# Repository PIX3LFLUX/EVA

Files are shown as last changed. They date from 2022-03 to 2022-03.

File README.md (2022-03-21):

# Electric slot Vehicle Automation (EVA)
An autonomous slot car for Carrera Digital 124 / 132, project with hardware and software components.
It's  written with PlatformIO using the Arduino framework.

## The Hardware
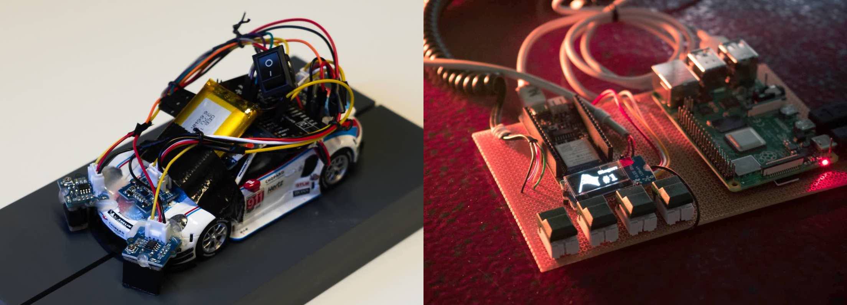
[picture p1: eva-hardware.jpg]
EVA Hardware


## General Information
This project was the author's Bachelor's Thesis at Hochschule Karlsruhe (HKA).
Documentation of the project as a whole is thus only available in german language.
The repository contents (including code comments) are english to ease adaption.

## Getting Started
### Prerequisites
- Python  
```
https://www.python.org/downloads/
```
Tick the "add to PATH" option just in case.
- Visual Studio Code  
```
https://code.visualstudio.com/Download
```
- PlatformIO IDE  
Open VSCode, then find the Extensions Marketplace on the left hand side or press Ctrl+Shift+X.
Search for "PlatformIO".
Once found, install it by clicking on "install".
- C/C++ Extension Pack  
Install it in the same way as PlatformIO IDE.

*Optional*
- Matlab  
```
https://www.mathworks.com/products/get-matlab.html
```
The project includes several Matlab scripts to aid development.
If Matlab is not available to You, try adjusting the syntax to use Octave instead.
```
https://www.gnu.org/software/octave/download
```

### Installation
- Download the code from this repository as a zip file.
- Unpack the archive into your working directory.
- Open VSCode.
- In VSCode, navigate to File > Open Folder or press Ctrl + K followed by Ctrl + O.
- Choose either "controller_emulator_status_monitor" or "datalogger_sensorcar" from this repository to open the respective project.
- In the EXPLORER on the left hand side, open the .vscode directory and click on c_cpp_properties.json. This will update the file to represent the paths on your development machine.
- On the bottom panel, click on the checkmark to build the project.
- Connect the ESP32 microcontroller to the development PC via USB.
- On the bottom panel, press the arrow pointing to the right to upload the code to the microcontroller.
- The code from "datalogger_sensorcar" is flashed to the vehicle, the code from "controller_emulator_status_monitor" is flashed to the stationary part of the system.
- To get a serial interface to the microcontroller for debugging, press the plug symbol on the bottom panel.
- Set up a Raspberry Pi 4 according to the instructions in "tools/pi-conf/instructions-to-setup-raspi" if output to a 1080p HDMI display is needed.  

*Optional*
- In VSCode, navigate to File > Preferences > Settings or press Ctrl+,.
- Search for "word wrap", then change "Editor: Word Wrap" from "off" to "on". The source code is designed to be viewed with word wrap.

## Usage
- You can find "globals.h" in the "include" folder using the EXPLORER on the left hand side.
- In both projects, this file is used to change behavior of the whole program easily.
- A description for every parameter is given as a comment in the file.
- State constants such as "SENSORCAR_IDLE_STATE" are not intended to be changed, as they are merely macros to make the code more readable.
- Extern variables that are declared in "globals.h" are initialized in "globals.cpp".
- The "tools" folder contains files that are used to assist development and are not required for functionaliy.

## Contributing
If you have a suggestion that would make this better, please fork the repository.
The author has finished development and will thus not be able to accept and process pull or feature requests.

## License
Distributed under the MIT License. See "LICENSE.txt" for more information.

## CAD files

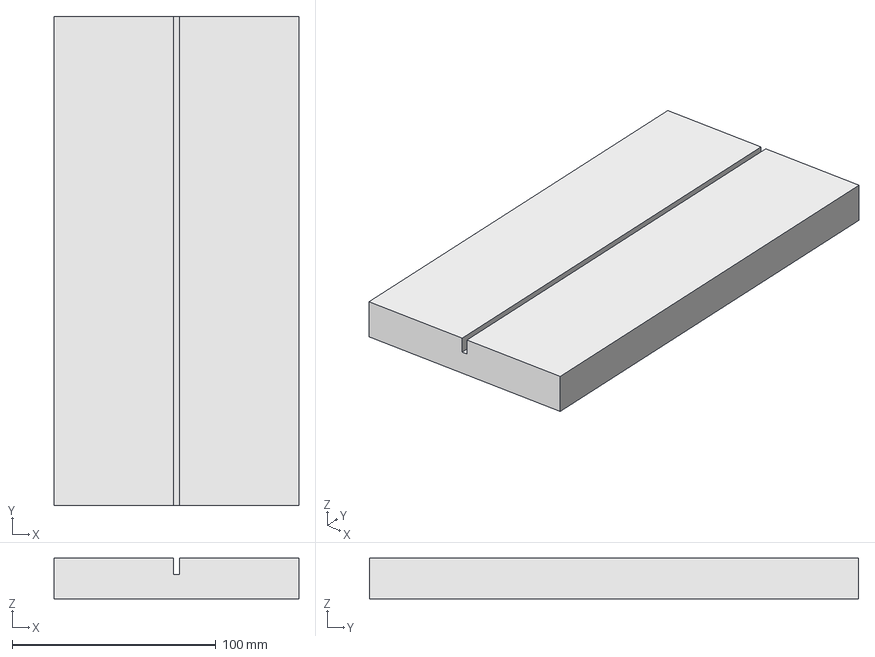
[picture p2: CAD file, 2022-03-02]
tools/imu-axes-calibration/calibration-block.FCStd
120.0 x 240.0 x 20.0 mm

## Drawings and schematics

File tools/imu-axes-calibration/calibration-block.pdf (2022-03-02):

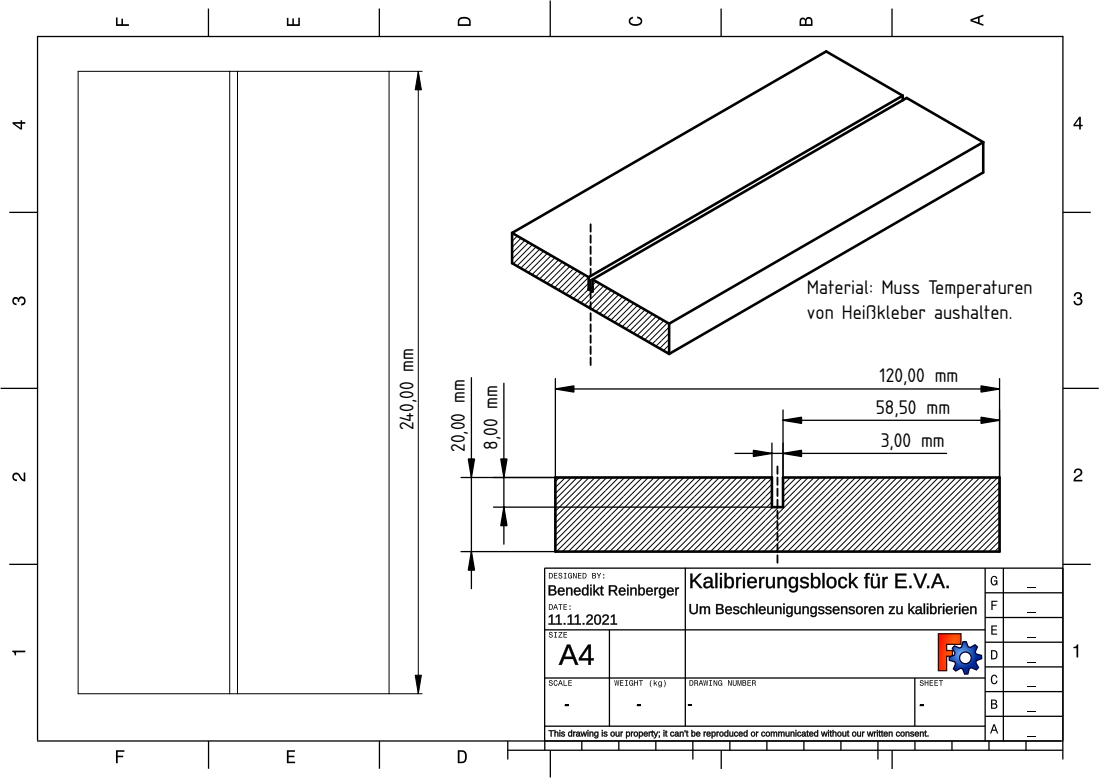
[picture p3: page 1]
aterial: M; erature; eiß; kle; alte

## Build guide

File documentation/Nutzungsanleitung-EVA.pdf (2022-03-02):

## EVA - Electric slot Vehicle Automation

## METHODEN UND HERAUSFORDERUNGEN

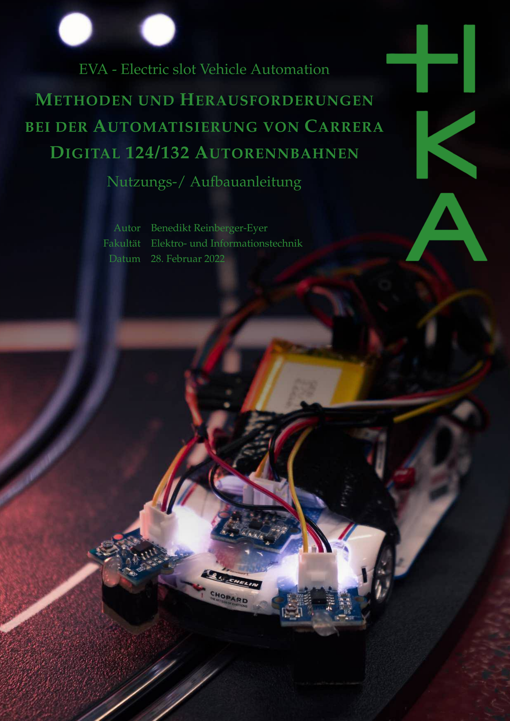
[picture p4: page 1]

## BEI DER AUTOMATISIERUNG VON CARRERA

## DIGITAL 124/132 AUTORENNBAHNEN

## Nutzungs-/ Aufbauanleitung

Autor Benedikt Reinberger-Eyer Fakultat Elektro- und Informationstechnik ¨ Datum 28. Februar 2022

## 1 Uber dieses Dokument ¨

Das Dokument zeigt einen moglichen Vorgang, mit dem das System EVA aufge- ¨ baut und in Betrieb genommen werden kann.

## 2 Aufbau der Control Unit

Zuerst muss die Rennstrecke aufgebaut werden. Dafur werden die gew ¨ | unschten ¨
Streckenteile ausgewahlt und ineinander gesteckt. Anschließend k ¨ | onnen die Strecken- ¨
teile mit den roten Verbindungshaken gesichert werden.

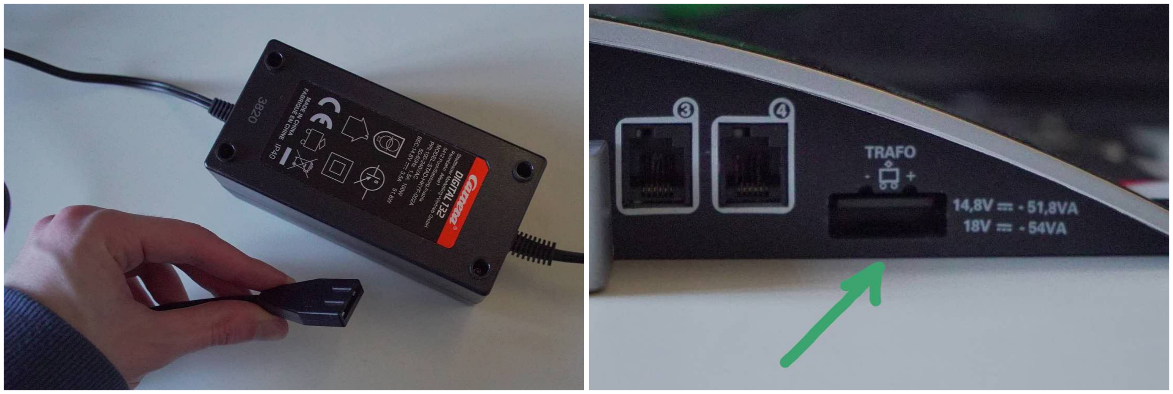
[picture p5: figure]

Ist die Strecke aufgebaut, so kann die Control Unit aufgesetzt werden. Zuerst muss der Stecker des Netzteils (links) in die Offnung an der Control Unit eingesteckt ¨ werden, die mit ”

TRAFO“ bezeichnet ist.

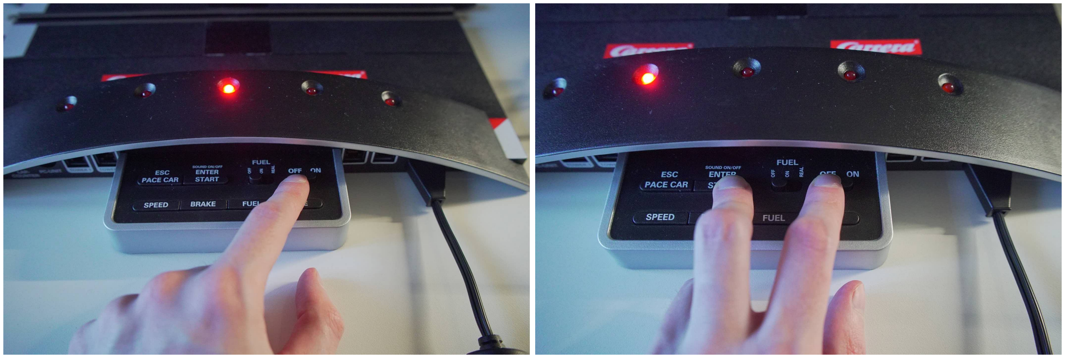
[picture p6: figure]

Soll der Ton so bleiben, wie er ist, kann der Ein-/Aus-Schieber in den ”
ON“ -
Zustand gebracht werden. Die mittlere LED sollte leuchten. Sollte sich die Control Unit im Laufe des Betriebs wegen Nichtnutzung abschalten (alle LEDs sind dann aus), so muss der Schieber in den ”

OFF“ -Zustand geschoben werden. Nach einer Wartezeit von 2...3 Sekunden kann diese dann wieder eingeschaltet werden. Soll die Tonwiedergabe ein- oder ausgeschaltet werden, so muss der ” START“
-Knopf gedruckt und gehalten werden, w ¨ | ahrend die Unit eingeschaltet wird. ¨

## 3 Aufbau des Handregler-Emulators

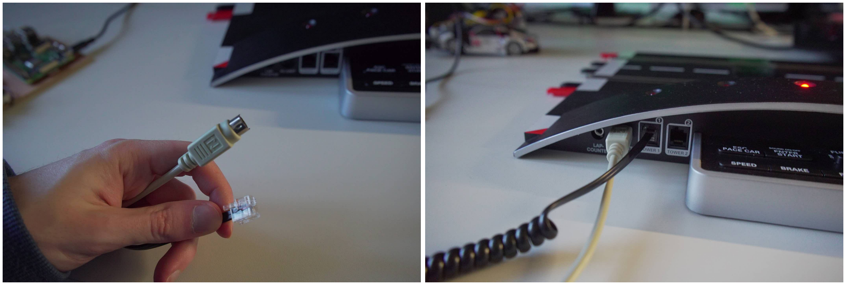
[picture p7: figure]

Zuerst sollten das serielle Kabel (grau) und das Handregler-Kabel (durchsichtig mit Nase) wie im linken Bild eingesteckt werden. Die Position des Handregler-Kabels ist wichtig fur die Funktion von EVA. Bitte das Handregler-Kabel daher ¨ nur in Port 1 stecken.

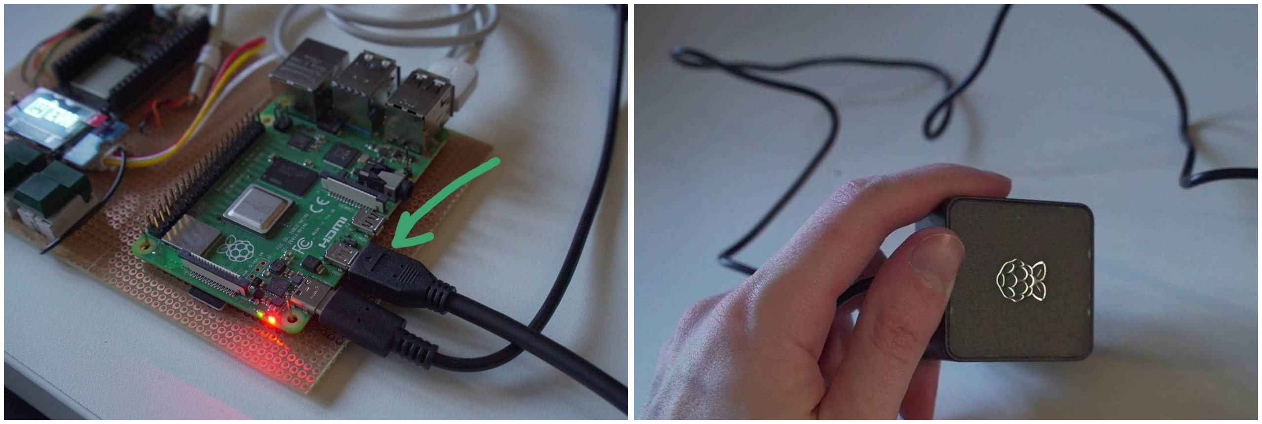
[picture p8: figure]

Nun sollte das externe Display mit HDMI an den Port des Raspberry Pi 4 angeschlossen werden, der naher am Rand bzw. USB-C Port ist. Das Display sollte eine ¨
Auflosung von ¨ | 1920x1080 (1080p) aufweisen, sonst wird die Ausgabe moglicherweise ¨
inkorrekt angezeigt. Anschließend kann das Netzteil mit dem Himbeerlogo (rechtes Bild) in die Steckdose eingesteckt werden.

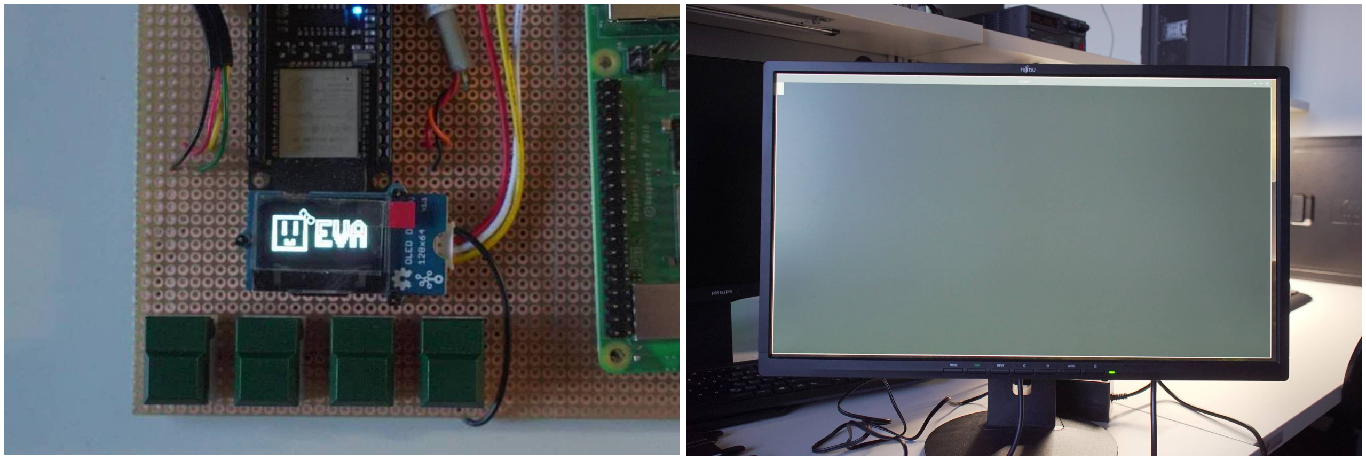
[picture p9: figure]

Es zeigt sich das EVA-Logo auf dem kleinen Display und nach einer Weile offnet ¨ sich auf dem großen Display ein graues Terminal. Der Handregler-Emulator ist nun bereit.

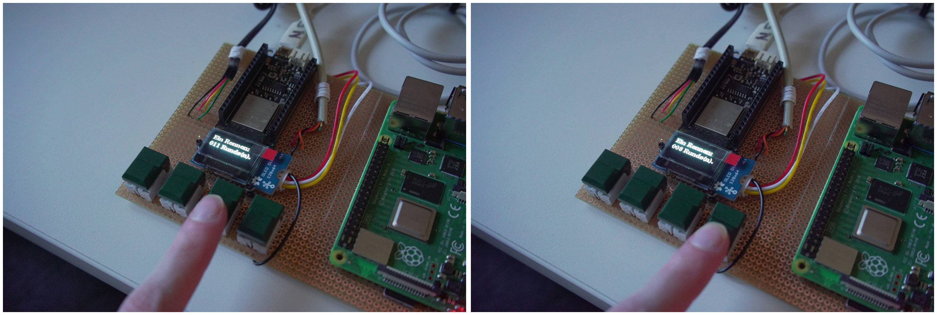
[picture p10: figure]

Um die Anzahl Runden in einem Rennen zu erhohen, kann der dritte gr ¨ | une Knopf ¨
von Links gedruckt werden (linkes Bild). Um die Anzahl Runden in einem Rennen ¨
zu verringern, kann der vierte grune Knopf von Links gedr ¨ | uckt werden (rechtes ¨
Bild).

## 4 Aufbau des Sensorautos

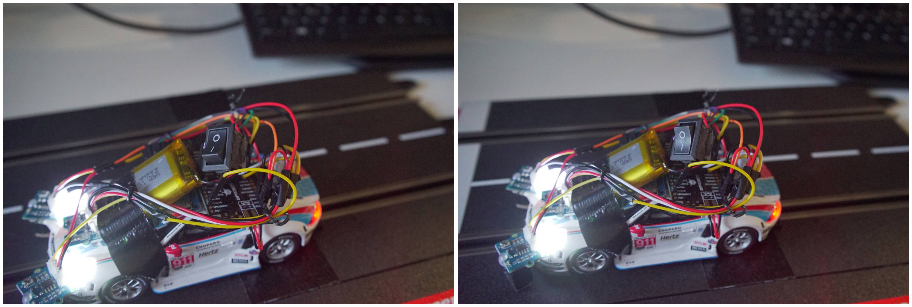
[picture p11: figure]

Ist das Auto auf der Schiene platziert, so kann der große Kippschalter betatigt wer- ¨ den, um den Akku mit der Elektronik zu verbinden. Zum Laden muss der Schalter auch eingeschaltet sein. Der Ladevorgang wird uber den USB-Mikro-Port auf der ¨
Unterseite der Platine (neben dem Steckverbinder fur den Akku) durchgef ¨ | uhrt. ¨

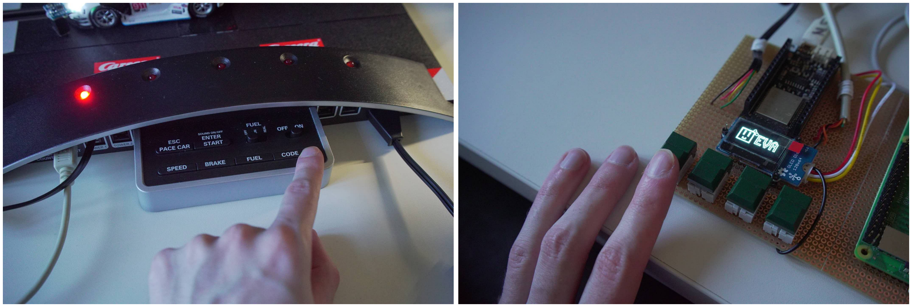
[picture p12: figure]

Ist das Auto noch nicht Handreglerport 1 an der Control Unit zugewiesen, so muss das getan werden. Dazu muss an der Control Unit die Taste ”
CODE“ gedruckt werden. Dann muss am Handregler-Emulator die erste Taste von Links ge- ¨ druckt werden. Die Eingabe wird durch Blinken der Scheinwerfer des Sensorautos ¨ bestatigt. ¨

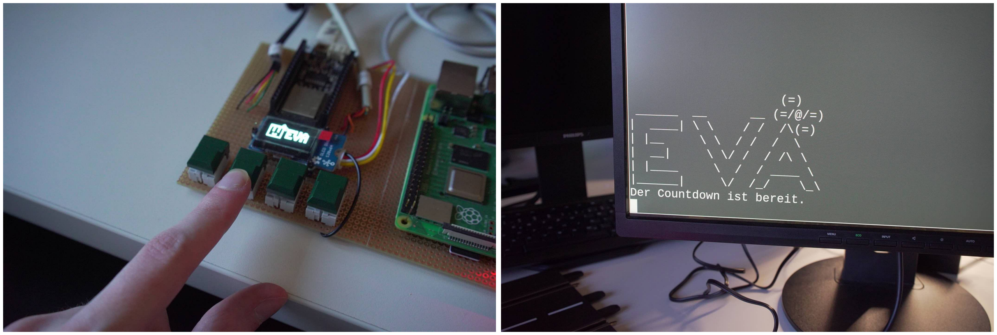
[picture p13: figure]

Nun ist das Sensorauto bereit, seine Erkundungsrunde zu fahren. Zuerst muss am Handregler-Emulator die zweite Taste von links gedruckt werden. Alternativ kann ¨ auch die ”

START“ -Taste an der Control Unit verwendet werden. Jetzt werden alle funf LEDs an der Control Unit leuchten, um Bereitschaft anzuzeigen. Auch am ¨ großen Display wird die Bereitschaft bestatigt (rechtes Bild). ¨

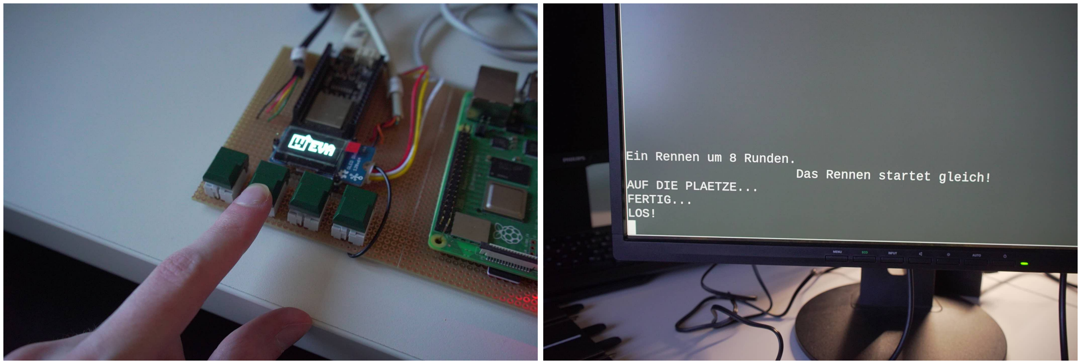
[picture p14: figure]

Ein erneutes Drucken der zweiten Taste von links f ¨ | uhrt zu einem Countdown. Al- ¨
ternativ kann auch die ” | START“ -Taste an der Control Unit verwendet werden.
Ist der Countdown beendet, so fahrt das Sensorauto automatisch eine Runde zum ¨ Erkunden der Strecke. Ist das Auto fertig, so bleibt es stehen. Es kennt nun die Strecke und muss nur neu eingelernt werden, wenn die Strecke geandert wird. ¨ Dazu muss es nur abgeschaltet werden und die Schritte von Sektion 4 mussen er- ¨ neut durchgefuhrt werden. ¨

## 5 Aufbau des menschengesteuerten Autos

Damit ein Mensch am Rennen teilnehmen kann, braucht er auch ein Auto.

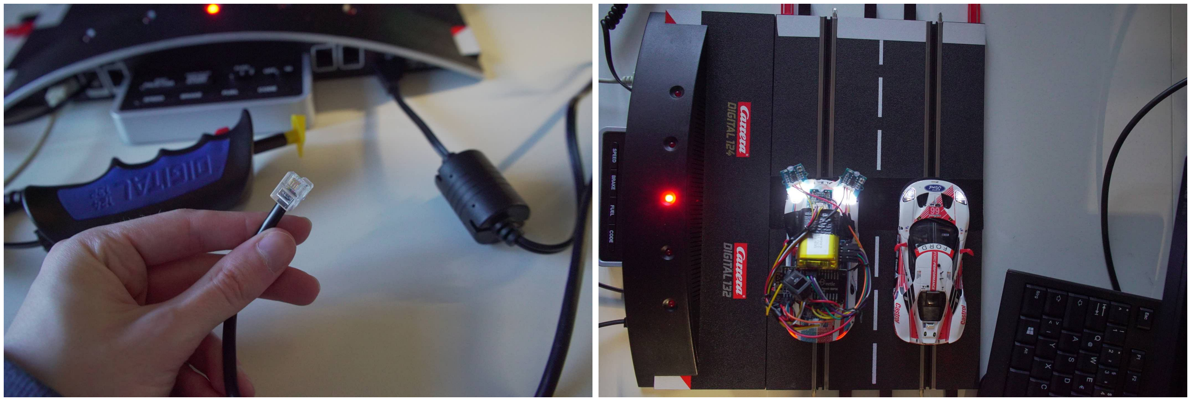
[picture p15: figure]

Zuerst muss der Handregler fur Menschen in die Control Unit eingesteckt werden. ¨ Ports 2...4 sind frei, Port 2 hat die niedrigste Eingabelatenz. Nun konnen beide Au- ¨ tos am Start/Ziel platziert werden. Die Zielline ist am vorderen Rand des schwarzen Klebebands (in Fahrtrichtung). Eine Platzierung weiter hinten kann zu einer
unabsichtlichen Rundenzahlung f ¨ | uhren. ¨

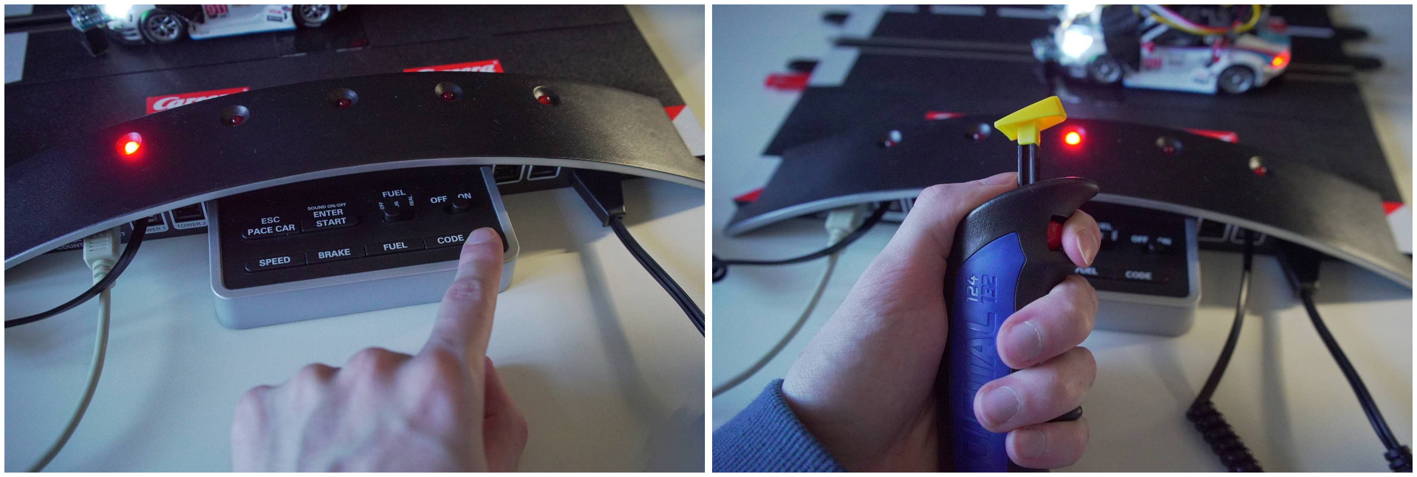
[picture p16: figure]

Ist das Auto noch nicht dem richtigen Port zugewiesen, so muss die Zuweisung erneut erfolgen. Dafur muss die ¨
”

CODE“ -Taste an der Control Unit wieder gedruckt werden und anschließend die rote Taste am Handregler. Alle Autos, die ¨ sich auf der Strecke befinden, werden bei einer Zuweisung zugewiesen. Wichtig ist also, dass sich nur das Auto von Interesse auf der Bahn befindet, wenn zugewiesen werden soll. Wieder bestatigt das Blinken der Scheinwerfer eine erfolgreiche ¨ Zuweisung.

## 6 Ende

Wurden die Schritte in dieser Reihenfolge durchgefuhrt, so sollte das System zum ¨ Rennen bereit sein. Betatigen der ¨
”

START“ -Taste oder der zweiten Handregler-Emulatortaste wie vorher bereits angesprochen kann zum Starten von Rennen genutzt werden. Das Rennen ist vorbei, wenn eines der zwei Autos die eingestellte Rundenzahl erreicht hat - das Sensorauto bleibt dann auch stehen.

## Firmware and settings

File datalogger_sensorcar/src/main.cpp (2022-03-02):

/* ###################################################
This code is intended to log sensor data to an SD card.
Additionally, it controls the car the sensors are on
by sending speed data over ESP-NOW to a second ESP32
running controller emulation.
################################################### */

#include "globals.h"                /* global constants */
#include <Arduino.h>
#include <cstdio>

#include "wireless_transmission.h"  /* libraries and functions for esp_now transmission */
#include "data_logging.h"           /* for logging sensor data to SD card */
#include "timer_setup.h"            /* for managing harware timer */
#include "imu_lsm6ds3.h"            /* for managing the two lsm6ds3 IMUs */
#include "ir_sensors.h"             /* for managing the two digital infrared reflectometers */
#include "track_data.h"             /* includes track parts lengths, etc. */

/* ###################################################
Variables
################################################### */

/* ####################################################
Functions
#################################################### */

/* sends speed value over ESP now if it changed */
inline void update_speed()
{
  if (speed_digital != speed_digital_previous)
  {
    send_data_wirelessly(speed_digital);
    speed_digital_previous = speed_digital;
  }
}

/* 
This task runs through a known number of speed control settings. Combined with data logging, the system response and other data can be aquired. In short, this tells the car what to do during data logging.
*/
IRAM_ATTR void measurement_task(void*)
{
  #if MEASURE_SYSTEM == MEASURE_MODE_SWEEP
    uint16_t speed_digital_test = VDIGI_INITIAL_VALUE; /* needs to hold more values to avoid overflow conditions. Also not reset at transition to idle state, contrary to speed_digital */
    bool          start_timestamp_set       = false;
    unsigned long timestamp_measure_start   = 0;
    unsigned long timestamp_measure_current = 0;

    for(;;)
    {
      if (xSemaphoreTake(measurement_timer_semaphore, portMAX_DELAY) == pdTRUE)
      {
        switch (sensorcar_state)
        {
          case SENSORCAR_IDLE_STATE:
            start_timestamp_set = false;
            reset_all_state_data(); /* also resets speed_digital */
            update_speed();         /* turn off engine after test */
          break;
          case SENSORCAR_MEASUREMENT_STATE:
            if (!start_timestamp_set) { timestamp_measure_start = millis(); start_timestamp_set = true; }
            timestamp_measure_current = millis();

            if (timestamp_measure_current >= (timestamp_measure_start + TIME_HELD_MS + TIME_MEASURE_MS) ) /* Measuring time has passed. Wrap up the current measurement. */
            {
              close_log_file();   /* save the progress */
              if ( (speed_digital_test + VDIGI_INCREMENT_VALUE) <= VDIGI_MAX_VALUE ) /* avoids overflow and checks for being smaller than VDIGI_MAX_VALUE*/
              {
                speed_digital_test += VDIGI_INCREMENT_VALUE; /* set up the speed for the next test */
              }
              else
              {
                #if DEBUG
                  Serial.println("Measurement complete. Goodbye!");
                #endif
                speed_digital = 0;    /* set speed to 0 here since the task will be deleted afterwards and will not have a chance then. */
                update_speed();
                sensorcar_state = SENSORCAR_IDLE_STATE;
                vTaskDelete(NULL);  /* task deletes itself */
              }              
              sensorcar_state = SENSORCAR_IDLE_STATE; /* measurement is complete, return to idle state */
            }
            else if (timestamp_measure_current >= (timestamp_measure_start + TIME_HELD_MS) ) /* Testing speed was held. Now slow down. */
            {
              speed_digital = 0;
              update_speed();
            }
            else if (timestamp_measure_current < (timestamp_measure_start + TIME_HELD_MS) ) /* TIME_HELD_MS milliseconds haven't passed yet, hold the testing speed. */
            {
              speed_digital = speed_digital_test;
              update_speed();           
            }
          break;
        }
      }
    }
  #endif
}

IRAM_ATTR void log_to_sdcard_task(void*)
{  
  /* SD card */
  const char LOG_FILE_HEADER[] = "Time\tTarget_Speed\tIR_Speed_Left\tIR_Speed_Right\tIR_Speed_Left_Trackbased\tIR_Speed_Right_Trackbased\tEstimated_Speed\tIR_Time_Difference_Left_Right\tAccel_Front_x\tAccel_Front_y\tAccel_Front_z\tRot_Front_x\tRot_Front_y\tRot_Front_z\tAccel_Heck_x\tAccel_Heck_y\tAccel_Heck_z\tRot_Heck_x\tRot_Heck_y\tRot_Heck_z\n";
  init_SD();
  init_log_file(LOG_FILE_HEADER);
  
  /* SD card initilized LED */
  pinMode(LED_BUILTIN, OUTPUT);
  digitalWrite(LED_BUILTIN, HIGH);

  for(;;)
  {
    if (xSemaphoreTake(logging_semaphore, portMAX_DELAY) == pdTRUE)
    {
      char log_write_buffer [200];
      #if CALIBRATE_ACCELERATION
        sprintf(log_write_buffer, "%d\t%d\t%lf\t%lf\t%lf\t%lf\t%lf\t%ld\t%lf\t%lf\t%lf\t%d\t%d\t%d\t%lf\t%lf\t%lf\t%d\t%d\t%d\n", 
          (int)imu_timestamp,
          (int)speed_digital,
          ir_left_speed,
          ir_right_speed,
          ir_left_speed_trackbased,
          ir_right_speed_trackbased,
          car_speed,
          ir_left_right_time_difference,
          front_imu_calibrated_acceleration_array[0],
          front_imu_calibrated_acceleration_array[1],
          front_imu_calibrated_acceleration_array[2],
          (int)front_imu_raw_data_array[0],
          (int)front_imu_raw_data_array[1],
          (int)front_imu_raw_data_array[2],    
          back_imu_calibrated_acceleration_array[0],
          back_imu_calibrated_acceleration_array[1],
          back_imu_calibrated_acceleration_array[2],
          (int)back_imu_raw_data_array[0],
          (int)back_imu_raw_data_array[1],
          (int)back_imu_raw_data_array[2]);
      #else
        sprintf(log_write_buffer, "%d\t%d\t%lf\t%lf\t%lf\t%lf\t%lf\t%ld\t%d\t%d\t%d\t%d\t%d\t%d\t%d\t%d\t%d\t%d\t%d\t%d\n", 
          (int)imu_timestamp,
          (int)speed_digital,
          ir_left_speed,
          ir_right_speed,
          ir_left_speed_trackbased,
          ir_right_speed_trackbased,
          car_speed,
          ir_left_right_time_difference,
          (int)front_imu_raw_data_array[3],
          (int)front_imu_raw_data_array[4],
          (int)front_imu_raw_data_array[5],
          (int)front_imu_raw_data_array[0],
          (int)front_imu_raw_data_array[1],
          (int)front_imu_raw_data_array[2],    
          (int)back_imu_raw_data_array[3],
          (int)back_imu_raw_data_array[4],
          (int)back_imu_raw_data_array[5],
          (int)back_imu_raw_data_array[0],
          (int)back_imu_raw_data_array[1],
          (int)back_imu_raw_data_array[2]);
      #endif
      appendFile(SD, LOG_FILE_NAME, log_write_buffer);
      #if DEBUG
        Serial.printf("Logged: %s\n", log_write_buffer);
      #endif
    }
  }
}

/* calculate arithmatic mean of two double values */
inline double_t mean_two_doubles(double_t x, double_t y)
{
  return (x + y) * 0.5;
}

/* gets new acceleration sample and performs integration (only when calibrated, else it makes little sense) to obtain a rough speed estimate */
IRAM_ATTR void sample_imu_task(void*)
{
  init_imu();
  for(;;)
  {
    if (xSemaphoreTake(sampling_semaphore, portMAX_DELAY) == pdTRUE)
    {
      switch (sensorcar_state)
      {
        case SENSORCAR_TRACK_MAPPING_STATE: /* fallthrough on purpose */
        case SENSORCAR_MEASUREMENT_STATE:
        case SENSORCAR_RACING_STATE:
          #if CALIBRATE_ACCELERATION
            accel_previous = mean_two_doubles(front_imu_calibrated_acceleration_array[0],back_imu_calibrated_acceleration_array[0]);
            imu_read(); /* takes about 685us to get all data via I2C */
            accel_now = mean_two_doubles(front_imu_calibrated_acceleration_array[0],back_imu_calibrated_acceleration_array[0]);
            car_speed += mean_two_doubles(accel_now, accel_previous) * SAMPLING_INTERVAL / 1e6 * GRAVITY_FACTOR; /* trapezoidal integration of acceleration value */
            #if DEBUG
              Serial.printf("accel_previous=%lf; accel_now=%lf; car_speed=%lf.\n", accel_previous, accel_now, car_speed);
            #endif
          #else
            imu_read();
          #endif
      
          #if DATA_LOGGING
            xSemaphoreGive(logging_semaphore);
          #endif
          break;
      }
    }
  }
}

inline double_t clamp_value_smaller(double_t value, double_t threshold)
{
  if (value < threshold)
  {
    return threshold;
  }
  else
  {
    return value;
  }
}

/* obtains time values from most recent IR sensor passing and processes it */
IRAM_ATTR void ir_sensor_process_task(void*)
{
  for(;;)
  {
    /* block task until both IR sensors have a new value */
    if (xSemaphoreTake(ir_data_semaphore, portMAX_DELAY) == pdTRUE)
    {
      switch (sensorcar_state)
      {
        #if (MEASURE_SYSTEM == MEASURE_MODE_SWEEP) && (OPERATION_MODE == MEASURING_MODE) /* measurement track only contains straights */
          case SENSORCAR_MEASUREMENT_STATE: /* fallthrough on purpose */
            if (!(ir_left_history_time && ir_right_history_time)) { break; } /* avoid divide by zero*/
            /* Derive speed from part length, which can be more accurate if only straights are used in the track since the absolute errors cancel each other out */
            ir_left_speed_trackbased = TRACKPIECE_LENGTH[TRACK_STRAIGHT] * 1.0e6 / ir_left_history_time;
            ir_right_speed_trackbased = TRACKPIECE_LENGTH[TRACK_STRAIGHT] * 1.0e6 / ir_right_history_time;
        #else
          case SENSORCAR_MEASUREMENT_STATE: /* fallthrough on purpose */
        #endif
        case SENSORCAR_RACING_STATE:
          /* Derive speed from the passing times */
          #if CALIBRATE_IR_SPEED
            ir_left_speed  = CAL_LEFT[0] * TAPE_WIDTH * 1.0e6 / ir_left_passing_time + CAL_LEFT[1]; /* v = s / t. t in us, so a correction factor of 10^6 is required. */
            ir_right_speed = CAL_RIGHT[0] * TAPE_WIDTH * 1.0e6 / ir_right_passing_time + CAL_RIGHT[1];
            ir_left_speed  = clamp_value_smaller(ir_left_speed, 0.0);  /* due to the calibration offset, negative values are possible. Those are clamped to 0. */
            ir_right_speed = clamp_value_smaller(ir_right_speed, 0.0);
          #else
            ir_left_speed  = TAPE_WIDTH * 1.0e6 / ir_left_passing_time; /* v = s / t. t in us, so a correction factor of 10^6 is required. */
            ir_right_speed = TAPE_WIDTH * 1.0e6 / ir_right_passing_time;            
          #endif
          /* Overwrite previous speed value to avoid drift from accelerometer values */
          #if MEASURE_SYSTEM == MEASURE_MODE_SWEEP
            car_speed = (ir_left_speed_trackbased + ir_right_speed_trackbased) / 2;
          #else
            car_speed = (ir_left_speed + ir_right_speed) / 2; /* TODO: figure out a smarter way to get accurate curve speed */
          #endif
          if (xSemaphoreTake(finish_line_passed_semaphore, 0) == pdTRUE)
          {
            /* Sync car position if it desynced somewhere on the track. Last segment was zero (because finish line has been passed), so this segment has to be 1. This assumes, however, that the latency from lapping to receiving it wirelessly is low enough that the car does not pass a mark in between. Should this be the case, the car will be out of sync by one. */            
            track_position_index = 1;
          }
          else
          {
            track_position_index += 1;
            track_position_index %= number_track_pieces;
          }
          break;
        case SENSORCAR_TRACK_MAPPING_STATE:
          if (xSemaphoreTake(finish_line_passed_semaphore, 0) == pdTRUE)
          {
            /* this part executes one segment after the finish line */
            number_track_pieces = track_position_index;
            calculate_track_checkpoint_lengths(number_track_pieces);
            track_mapped_out_flag = true;
            #if DATA_LOGGING
              close_log_file();
            #endif
            #if DEBUG
              Serial.printf("Estimated track: {");
              for(uint8_t ii=0; ii < number_track_pieces; ii++) { Serial.printf(" %d", track_geometry[ii]); }
              Serial.printf("}\n");
            #endif
          }
          else
          {
            /* determine what kind of piece the last track piece was, then update the position. */
            track_geometry[track_position_index] = determine_track_piece(ir_left_right_time_difference);
            track_position_index += 1;
          }
      }
    }
  }
}

inline uint8_t increment_with_boundaries(uint8_t value, uint8_t increment, uint8_t modulo_divisior)
{
  return uint8_t(((uint16_t(value) + uint16_t(increment)) % uint16_t(modulo_divisior))); /* typecast to avoid overflow */
}

/* inefficient but highly functional. Faster search algorithms exist, but are not required. */
inline uint8_t find_closest_legal_vdigi(float value)
{
  uint8_t closest_value       = 0;
  float   smallest_difference = 10e3; /* init with big value*/
  float   current_difference  = 0.0;

  /* step through array and find the smallest absolute difference to the current value */
  for(uint8_t ii = 0; ii < sizeof(AVAILABLE_VDIGI); ii++)
  {
    current_difference = abs(float(AVAILABLE_VDIGI[ii]) - value);
    if ( current_difference < smallest_difference)
    {
      smallest_difference = current_difference;
      closest_value = AVAILABLE_VDIGI[ii];
    }
  }

  return closest_value;
}

inline uint8_t simple_algorithm(uint8_t track_position_index, uint8_t number_track_pieces, uint8_t* track_geometry)
{           
  /*
    'increment_with_boundaries(track_position_index, 1, number_track_pieces)' identifies the next track piece index (0...number_track_pieces-1)
    'track_geometry[index]' is a look up table (LUT) for the type of segment any piece of the track is (for example, a TRACK_STRAIGHT or TRACK_CURVE_LEFT_INNER_TRACK)
    'TARGET_TRACKPIECE_SPEED_DIGITAL[segment_type]' is a LUT for the target vdigi that should be driven on a specific type of track piece.
  */
  return TARGET_TRACKPIECE_SPEED_DIGITAL[track_geometry[increment_with_boundaries(track_position_index, 1, number_track_pieces)]];
}

inline uint8_t average_algorithm(uint8_t track_position_index, uint8_t number_track_pieces, uint8_t* track_geometry)
{
  uint sum_buffer = 0;
  for(uint8_t ii = 0; ii < ALGORITHM_AVERAGE_NUMBER; ii++)
  {
    sum_buffer += TARGET_TRACKPIECE_SPEED_DIGITAL[track_geometry[increment_with_boundaries(track_position_index, ii+1, number_track_pieces)]];
  }
  
  return find_closest_legal_vdigi( float(sum_buffer)/float(ALGORITHM_AVERAGE_NUMBER) );
}

IRAM_ATTR void velocity_controller_task(void*)
{
  for(;;)
  {
    /* execute every CONTROLLER_INTERVAL microseconds */
    if (xSemaphoreTake(controller_timer_semaphore, portMAX_DELAY) == pdTRUE)
    {
      switch (sensorcar_state)
      {
        case SENSORCAR_IDLE_STATE:
          reset_all_state_data();
          update_speed();
        break;
        case SENSORCAR_RACING_STATE:
          #if ALGORITHM_TYPE == ALGORITHM_SIMPLE
            /* depending on the next track piece, set a target speed
            '(track_position_index + 1) % number_track_pieces' identifies the next track piece index (0...number_track_pieces-1)
            'track_geometry[index]' is a look up table (LUT) for the type of segment any piece of the track is (for example, a TRACK_STRAIGHT or TRACK_CURVE_LEFT_INNER_TRACK)
            'MAXIMUM_TRACKPIECE_SPEED_DIGITAL[segment_type]' is a LUT for the maximum speed allowed on a specific type of track piece.
            */
            speed_digital = simple_algorithm(track_position_index, number_track_pieces, track_geometry);
          #elif ALGORITHM_TYPE == ALGORITHM_AVERAGE
            speed_digital = average_algorithm(track_position_index, number_track_pieces, track_geometry);
          #endif
          update_speed();
          break;
        case SENSORCAR_TRACK_MAPPING_STATE:
          if (track_mapped_out_flag)
          {
            speed_digital = 0;
          }
          else
          {
            speed_digital = 40;
          }
          update_speed();
          break;
      }
    }
  }
}

/* #####################################################
Initialization
##################################################### */
void setup()
{
  /* serial interface */
  Serial.begin(115200);
  Serial.setTimeout(10);
  
  /* wireless comms */
  init_wifi();

  /* ir sensors */
  init_ir_sensors();

  /* timers */
  init_timers();

  /* Tasks. Some Tasks do their own initialization to avoid memory bugs with this version of FreeRTOS. */

  #if (OPERATION_MODE==MEASURING_MODE)
    xTaskCreatePinnedToCore(log_to_sdcard_task,       "log_to_sdcard_task",       10000, NULL, DATA_LOG_PRIO      ,       &log_to_sdcard_task_handle,       DATA_LOG_CORE);
    xTaskCreatePinnedToCore(measurement_task,         "measurement_task",         10000, NULL, MEASUREMENT_PRIO ,         &measurement_task_handle,         MEASUREMENT_CORE);
  #else
    xTaskCreatePinnedToCore(velocity_controller_task, "velocity_controller_task", 10000, NULL, VELOCITY_CONTROLLER_PRIO,  &velocity_controller_task_handle, VELOCITY_CONTROLLER_CORE);
  #endif

  xTaskCreatePinnedToCore(sample_imu_task,          "sample_imu_task",          10000, NULL, IMU_SAMPLE_PRIO,           &sample_imu_task_handle,         IMU_SAMPLE_CORE);
  xTaskCreatePinnedToCore(ir_sensor_process_task,   "ir_sensor_process_task",   10000, NULL, IR_SENSOR_PROCESS_PRIO,    &ir_sensor_process_task_handle,  IR_SENSOR_PROCESS_CORE);
}

/* #####################################################
Main Loop
##################################################### */
void loop()
{
  /* This loop does nothing, every function of the firmware is implemented in tasks. */
  DELAY_N_MS(portMAX_DELAY); /* block task forever */
}

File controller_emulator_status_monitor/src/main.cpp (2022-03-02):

/* ###################################################
This is the receiver and controller emulator code.
It also communicates with the Carrera CU to obtain lap times and start races.
################################################### */

#include "globals.h"          /* constants, functions and variables used by multiple files */
#include "button_handling.h"
#include "serial_handling.h"  /* For communication with the control unit and wireless comms as well as processing the data. The bulk of the code lives here. */

/* ###################################################
Functions
################################################### */
inline void display_race_lap_number()
{
  #if DEBUG
    Serial.printf("Lap count for race to finish: %d\n", number_laps_in_race);
  #endif
  #if SERIAL_USERDATA_PRINT
    Serial.print(TEXT_PUSH_DOWN_STRING);
    Serial.printf("Ein Rennen um %d Runden.\n", number_laps_in_race);
  #endif
  #if DISPLAY_OUTPUT_ENABLE
    display_128x64.setFont(u8g2_font_ncenB12_tr);
    display_128x64.drawStr(0, 20,"Ein Rennen:");
    display_128x64.setCursor(0, 40);
    display_128x64.print(u8x8_u8toa(number_laps_in_race, 3)); /* ensures that the number of laps is always a consistent length of characters when being printed. Appends zeros */
    display_128x64.print(" Runde(n).");
    display_128x64.sendBuffer();
    display_128x64.clearBuffer();  
  #endif  
}

inline void display_eva_logo()
{
    display_128x64.drawXBM(0,0,eva_splashscreen_width,eva_splashscreen_height, eva_splashscreen_bits);
    display_128x64.sendBuffer();
    display_128x64.clearBuffer();
}

/*
Deferred interrupt handling for buttons, because they are not THAT time-critical and it keeps the time spent in interrupt service routine to a minimum.
After the buttons have been processed, the task blocks until a button is pressed again.
The buttons on the control unit work without delay, since there is no serial communication required to operate them.
Note however that the software is not designed to operate with those.
It will work for the most part, but there might be some unintuitive behavior.
*/
IRAM_ATTR void button_handle_task(void*)
{
  init_buttons();
  for(;;) 
  {
    if (xSemaphoreTake(button_pressed_semaphore, portMAX_DELAY) == pdTRUE)
    {
      /* nested ifs to ensure only one button is processed at a time. Priority: start button > increase laps in race > decrease laps in race */
      if (start_button_state)
      {
        press_start_button();
        #if DEBUG
          Serial.println("Start button pressed.");
        #endif
        #if DISPLAY_OUTPUT_ENABLE
          display_eva_logo();
        #endif
      }
      else
      {
        if (increase_laps_button_state)
        {
          /* protection from overflow */
          if (number_laps_in_race < 255)  { number_laps_in_race += 1; }
          else                            { number_laps_in_race  = 255; }
          #if DEBUG || SERIAL_USERDATA_PRINT || DISPLAY_OUTPUT_ENABLE
            display_race_lap_number();
          #endif
        }
        else
        {
          if (decrease_laps_button_state)
          {
            /* protection from underflow and omission of 0-lap races, since they are nonsensical and functionally equivalent to 1-lap races */
            if (number_laps_in_race > 1)  { number_laps_in_race -= 1; }
            else                          { number_laps_in_race  = 1; }
            #if DEBUG || SERIAL_USERDATA_PRINT || DISPLAY_OUTPUT_ENABLE
              display_race_lap_number();
            #endif  
          }
        }
      }
    }
  }
}

IRAM_ATTR void serial_communication_with_control_unit_task(void*)
{
  for(;;)
  {
    get_data_from_control_unit();
    taskYIELD(); /* If a task with higher priority is available (=not blocking), it well get executed. Else, this task gets executed again */
  }
}

IRAM_ATTR void print_car_data_task(void*)
{
  #if DISPLAY_OUTPUT_ENABLE
    init_display();
  #endif  
  for(;;)
  {
    /* 
    If new data has arrived, present it over serial or on the display, depending on the configuration in globals.h 
    After it has been presented, block the task until there is new data available
    */
    if ( xSemaphoreTake(print_data_semaphore,portMAX_DELAY) == pdTRUE )
    {
      print_car_data();
    }
  }
}

/* 
This task checks the light state of the control unit (five leds on top) to synchronize its internal state to it.
It is executed only if the light state has changed.
When the light state has been examined and acted upon, the task blocks again.
*/
IRAM_ATTR void process_light_state_task(void*)
{
  for(;;)
  {
    if ( xSemaphoreTake(process_light_state_semaphore,portMAX_DELAY) == pdTRUE )
    {
      process_light_state();
    }
  }
}

/* ###################################################
Initilization
################################################### */
void setup()
{
  /* Serial interfaces */
  Serial.begin(115200); /* Debug interface */
  init_serial2();       /* Control Unit serial interface */

  /* DAC */
  init_dac();
  
  /* Wi-Fi */
  init_wifi();

  /* Tasks
  main loop runs on core 1.
  Some tasks run their own inits to make sure the globals are initialized on the same core where they are used.
  Sometimes there's problems if that is not the case.
  That's a bug with the multicore port of FreeRTOS on the ESP32.
  */
  xTaskCreatePinnedToCore(button_handle_task, 
                          "button_handle_task", 
                          10000,
                          NULL,
                          BUTTON_HANDLE_PRIO, 
                          NULL,
                          BUTTON_HANDLE_CORE);
  xTaskCreatePinnedToCore(serial_communication_with_control_unit_task,
                          "serial_communication_with_control_unit_task",
                          10000,
                          NULL,
                          SERIAL2_COMMS_PRIO,
                          NULL,
                          SERIAL2_COMMS_CORE);
  xTaskCreatePinnedToCore(print_car_data_task, 
                          "print_car_data_task", 
                          10000,
                          NULL,
                          PRINT_DATA_PRIO, 
                          NULL,
                          PRINT_DATA_CORE);
  xTaskCreatePinnedToCore(process_light_state_task, 
                          "process_light_state_task", 
                          10000,
                          NULL,
                          LIGHT_STATE_PRIO, 
                          NULL,
                          LIGHT_STATE_CORE);                       
}

/* ###################################################
Main Loop
################################################### */
void loop()
{
  DELAY_N_MS(portMAX_DELAY); /* block Task indefinitely */
}

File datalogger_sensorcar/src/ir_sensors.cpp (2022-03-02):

#include "ir_sensors.h"

/* get ports and masks for faster digital reads so that it will be OK to read in the isr */
const uint32_t IR_SENSOR_LEFT_PIN_MASK      = digitalPinToBitMask(IR_SENSOR_LEFT_PIN);
const uint32_t IR_SENSOR_RIGHT_PIN_MASK     = digitalPinToBitMask(IR_SENSOR_RIGHT_PIN);

volatile uint32_t* IR_SENSOR_LEFT_PIN_PORT  = portInputRegister(digitalPinToPort(IR_SENSOR_LEFT_PIN));
volatile uint32_t* IR_SENSOR_RIGHT_PIN_PORT = portInputRegister(digitalPinToPort(IR_SENSOR_RIGHT_PIN));

/* time variables */
DRAM_ATTR unsigned long ir_left_trigger_timestamp   = 0; 
DRAM_ATTR unsigned long ir_right_trigger_timestamp  = 0;
DRAM_ATTR unsigned long ir_left_trigger_timestamp_previous   = 0; 
DRAM_ATTR unsigned long ir_right_trigger_timestamp_previous  = 0; 

DRAM_ATTR unsigned long ir_left_passing_time        = 0; /* time the pin was low in us */
DRAM_ATTR unsigned long ir_right_passing_time       = 0; /* time the pin was low in us */
DRAM_ATTR unsigned long ir_left_history_time        = 0; /* time between two tape passings */
DRAM_ATTR unsigned long ir_right_history_time       = 0; /* time between two tape passings */

DRAM_ATTR signed long ir_left_right_time_difference = 0; /* time (in us) it takes the right ir sensor to trigger after the left one triggered. can be used to detect curves. */

/* logic */
DRAM_ATTR bool left_done = false;   /* data is only ready when both left and right sensors are done reading */
DRAM_ATTR bool right_done = false;  /* data is only ready when both left and right sensors are done reading */

DRAM_ATTR Ticker left_debounce_timer;
DRAM_ATTR Ticker right_debounce_timer;

void init_ir_sensors()
{
    pinMode(IR_SENSOR_LEFT_PIN, INPUT_PULLUP);
    pinMode(IR_SENSOR_RIGHT_PIN, INPUT_PULLUP);
    attachInterrupt(IR_SENSOR_LEFT_PIN, ir_sensor_left_trigger,     CHANGE);
    attachInterrupt(IR_SENSOR_RIGHT_PIN, ir_sensor_right_trigger,   CHANGE);
}

/* reads true for a pin == '0' and false for a pin == '1'. Inverts the logic so it's normal again, since the IR sensors give a LOW signal when they detect the tape.*/
inline bool inverted_fast_digital_read(uint32_t mask, volatile uint32_t* port)
{
    return (*port & mask) == 0;
}

IRAM_ATTR void ir_sensor_left_trigger()
{
    left_debounce_timer.once_ms(DEBOUNCE_TIMEOUT_MS, ir_sensor_left_isr);
}

IRAM_ATTR void ir_sensor_right_trigger()
{
    right_debounce_timer.once_ms(DEBOUNCE_TIMEOUT_MS, ir_sensor_right_isr);
}

IRAM_ATTR void ir_sensor_left_isr()
{
    if ( inverted_fast_digital_read(IR_SENSOR_LEFT_PIN_MASK, IR_SENSOR_LEFT_PIN_PORT) )
    {
        /* driving onto reflective surface */
        ir_left_trigger_timestamp_previous = ir_left_trigger_timestamp;
        ir_left_trigger_timestamp = micros();
        ir_left_history_time = ir_left_trigger_timestamp - ir_left_trigger_timestamp_previous;
        left_done = false;
    }
    else
    {
        /* driving off of reflective surface */
        ir_left_passing_time = micros() - ir_left_trigger_timestamp;
        
        left_done = ir_left_passing_time > SHORTEST_PASSING_TIME; /* check value for validity. If it is longer than the SHORTEST_PASSING_TIME, we are done reading. */
        if (left_done && right_done)
        {
            ir_left_right_time_difference = ir_right_trigger_timestamp - ir_left_trigger_timestamp;
            #if DEBUG
                Serial.printf("Infrared sensor left was high for %ld us.\n", ir_left_passing_time);
                Serial.printf("Infrared sensor right was high for %ld us.\n", ir_right_passing_time);
                Serial.printf("Infrared sensor right triggered %ld us after the left one.\n", ir_left_right_time_difference);            
            #endif            
            xSemaphoreGiveFromISR(ir_data_semaphore,NULL);
            left_done = false;
            right_done = false;
        }
    }
}

IRAM_ATTR void ir_sensor_right_isr()
{
    if ( inverted_fast_digital_read(IR_SENSOR_RIGHT_PIN_MASK, IR_SENSOR_RIGHT_PIN_PORT) )
    {
        /* driving onto reflective surface */
        ir_right_trigger_timestamp_previous = ir_right_trigger_timestamp;
        ir_right_trigger_timestamp = micros();
        ir_right_history_time = ir_right_trigger_timestamp - ir_right_trigger_timestamp_previous;
        right_done = false;
    }
    else
    {
        /* driving off of reflective surface */
        ir_right_passing_time = micros() - ir_right_trigger_timestamp;
        
        right_done = ir_right_passing_time > SHORTEST_PASSING_TIME;
        if (left_done && right_done)
        {
            ir_left_right_time_difference = ir_right_trigger_timestamp - ir_left_trigger_timestamp;
            #if DEBUG
                Serial.printf("Infrared sensor left was high for %ld us.\n", ir_left_passing_time);
                Serial.printf("Infrared sensor right was high for %ld us.\n", ir_right_passing_time);
                Serial.printf("Infrared sensor right triggered %ld us after the left one.\n", ir_left_right_time_difference);
            #endif
            xSemaphoreGiveFromISR(ir_data_semaphore,NULL);
            left_done = false;
            right_done = false;
        }
    }
}

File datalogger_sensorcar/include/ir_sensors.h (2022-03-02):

#include "globals.h"
#include <Ticker.h>

#define IR_SENSOR_LEFT_PIN      16      /* pin for the digital signal */
#define IR_SENSOR_RIGHT_PIN     27

#define DEBOUNCE_TIMEOUT_MS     1

#define TAPE_WIDTH              20e-3   /* tape width in meters */
#if CALIBRATE_IR_SPEED
    const double_t CAL_LEFT[] =   {2.47510363770948, -1.03939098433124}; /* calibration parameter that accounts for detection of tape without being at it's edges (usually being close to the tape already triggers detection, effectively making it bigger), slope and offset */
    const double_t CAL_RIGHT[] =  {2.27465000160550, -0.928610854146550};
#endif
#define MAXIMUM_POSSIBLE_SPEED  20      /* in m/s, needed for calculation of SHORTEST_PASSING_TIME*/
#define SHORTEST_PASSING_TIME   TAPE_WIDTH/MAXIMUM_POSSIBLE_SPEED*1e6 /* in us. If a time shorter than this is measured, it is likely a measurement error. */

extern unsigned long ir_left_passing_time;
extern unsigned long ir_right_passing_time;
extern unsigned long ir_left_history_time;
extern unsigned long ir_right_history_time;
extern signed long ir_left_right_time_difference;

void init_ir_sensors();
inline bool inverted_fast_digital_read(uint32_t mask, volatile uint32_t* port);
IRAM_ATTR void ir_sensor_left_trigger();    /* starts a debouncing timer */
IRAM_ATTR void ir_sensor_right_trigger();   /* starts a debouncing timer */
IRAM_ATTR void ir_sensor_left_isr();
IRAM_ATTR void ir_sensor_right_isr();
